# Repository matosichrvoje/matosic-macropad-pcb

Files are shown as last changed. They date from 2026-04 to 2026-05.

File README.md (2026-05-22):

# Matosic Macropad

**Open source programmable keypad with 9 mechanical switches and a clickable rotary encoder.**

A derivative of [ANAVI Macro Pad 10](https://github.com/AnaviTechnology/anavi-macro-pad-10) by [ANAVI Technology](http://www.anavi.technology), redesigned around a Seeeduino XIAO module socket and migrated to KiCad 10. Released under the same Creative Commons Attribution-ShareAlike 4.0 International License (CC-BY-SA-4.0) as the upstream — see [LICENSE](LICENSE).

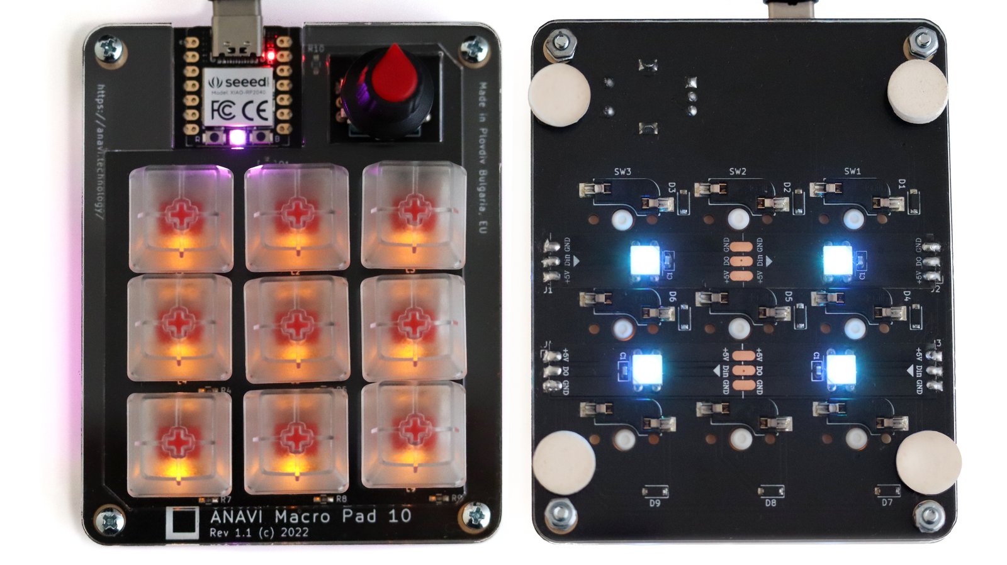
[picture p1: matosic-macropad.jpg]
Matosic Macropad


## Hardware

- 9× Cherry MX (Kailh hot-swap sockets) wired as a 3×3 matrix with per-key 1N4148 anti-ghosting diodes
- 1× clickable EC11 rotary encoder
- **Seeeduino XIAO module socket** — supports any XIAO variant (XIAO RP2040 recommended). USB-C connector and microcontroller live on the XIAO, not on this PCB.
- 9× per-key 1206 SMD LED backlight (single on/off, driven via SOT-23 NPN — not WS2812B)
- 4× 1×3 expansion headers (only J1 carries signal — `R10 → board.D10`; J2/J3/J4 are +5V/GND power taps)
- Designed in KiCad 10 (migrated from the upstream KiCad 5 source)

## Companion firmware

CircuitPython firmware lives in a separate repo: <https://github.com/matosichrvoje/matosic-macropad-firmware>

XIAO pin map for the 3×3 matrix scan and LED chain is documented in [firmware-pinout.md](firmware-pinout.md).

## Case

OpenSCAD sources plus ready-to-print STL/STEP exports live under [case/](case/). Re-export from the `.scad` files after any edit.

## Manufacturing

Target fab is JLCPCB; PCBA is optional (only commodity SMT parts on the board, all hand-solderable). The verified BOM with confirmed LCSC part numbers from the v0.0.0.17 fab run is committed at [bom/matosic-macropad-bom.csv](bom/matosic-macropad-bom.csv) — use it as the source of truth instead of relying on JLCPCB's auto-match. Gerbers + CPL are generated locally by the KiCad **Fabrication Toolkit** plugin into `production/` (gitignored).

## Changes from upstream

This is a derivative work. The substantive changes relative to `AnaviTechnology/anavi-macro-pad-10` are:

- KiCad 5 → KiCad 10 project migration (project file, schematic, PCB, library tables)
- Rebrand from "ANAVI Macro Pad 10" to "Matosic Macropad" — new silkscreen artwork and logo footprint at [components/logo.pretty/matosic-logo.kicad_mod](components/logo.pretty/matosic-logo.kicad_mod). The original Anavi logo footprint is retained at [components/logo.pretty/anavi-logo.kicad_mod](components/logo.pretty/anavi-logo.kicad_mod) for provenance.
- Verified LCSC part numbers for JLCPCB PCBA in [bom/matosic-macropad-bom.csv](bom/matosic-macropad-bom.csv); fab learnings and corrections documented in [CLAUDE.md](CLAUDE.md)
- Renamed all KiCad project files from `anavi-macro-pad-10.*` to `matosic-macropad.*`

The 3×3 switch matrix, encoder wiring, LED-chain topology (single NPN driving 9 LEDs from one GPIO), Kailh hot-swap socket footprint, Seeeduino XIAO module socket footprint, and the case design are inherited from the upstream design.

## Repository files

- `matosic-macropad.kicad_pro`, `matosic-macropad.kicad_pcb`, `matosic-macropad.kicad_sch` — active KiCad 10 project
- `matosic-macropad.sch`, `matosic-macropad.pro`, `matosic-macropad-cache.lib` — pre-migration KiCad 5 backups, kept for safety
- [components/](components/) — bundled footprint/symbol libraries (keyswitches, LEDs, XIAO, logos)
- [case/](case/) — OpenSCAD case sources + STL/STEP exports
- [bom/](bom/) — verified BOM with LCSC part numbers
- [firmware-pinout.md](firmware-pinout.md) — authoritative XIAO pin map for the firmware repo

## Credits

- **Lead:** Hrvoje Matosic
- **Contributors:** Jorge Ochoa, Iván Aceves, Iván Estevez
- **Upstream design:** [ANAVI Technology](http://www.anavi.technology) — *ANAVI Macro Pad 10*, the original work this project is derived from.

## License

This project is released under the [Creative Commons Attribution-ShareAlike 4.0 International (CC-BY-SA-4.0)](https://creativecommons.org/licenses/by-sa/4.0/) license, matching the upstream. The full license text and attribution notice are in [LICENSE](LICENSE).

If you remix or build on this design, you must:

1. **Attribute** Hrvoje Matosic and link back to this repository.
2. **Attribute** the upstream project — [ANAVI Macro Pad 10](https://github.com/AnaviTechnology/anavi-macro-pad-10) by [anavi.technology](http://www.anavi.technology) — as the original design.
3. **ShareAlike** — license your derivative under CC-BY-SA-4.0 (or a BY-SA-compatible license).
4. Indicate what you changed relative to this repo.

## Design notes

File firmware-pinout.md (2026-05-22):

# Firmware pinout — v0.0.0.17

Derived from [matosic-macropad.kicad_pcb](matosic-macropad.kicad_pcb) on 2026-05-18 during the first board bring-up. Use this map when porting [code.py](https://github.com/matosichrvoje/matosic-macropad-firmware/blob/main/code.py) to XIAO RP2040.

## XIAO U1 pin map

The U1 footprint is `xiao:Seeeduino XIAO-MOUDLE14P-2.54-21X17.8MM`. Numbering matches the standard Seeed silkscreen — pin 1 at top-left, pin 14 at top-right.

| KiCad pad | XIAO silk | CircuitPython | Function |
|---|---|---|---|
| 1  | D0  | `board.D0`  | LED enable (Q1 gate) — high turns all 9 LEDs on |
| 2  | D1  | `board.D1`  | ROW 3 — SW7/SW8/SW9 common |
| 3  | D2  | `board.D2`  | ROW 2 — SW4/SW5/SW6 common |
| 4  | D3  | `board.D3`  | ROW 1 — SW1/SW2/SW3 common |
| 5  | D4  | `board.D4`  | COL 1 — outputs of diodes D1/D4/D7 |
| 6  | D5  | `board.D5`  | COL 2 — outputs of diodes D2/D5/D8 |
| 7  | D6  | `board.D6`  | COL 3 — outputs of diodes D3/D6/D9 |
| 8  | D7  | `board.D7`  | Encoder phase B |
| 9  | D8  | `board.D8`  | Encoder phase A |
| 10 | D9  | `board.D9`  | Encoder push-switch |
| 11 | D10 | `board.D10` | Side-connector signal (R10 → J1 pad 2) |
| 12 | 3V3 | — | Power |
| 13 | GND | — | Power |
| 14 | 5V  | — | Power (LED rail through Q1) |

## Key matrix

3×3 with per-key anti-ghosting diodes (D1–D9, 1N4148 SOD-123). Scan by driving each row LOW in turn and reading the column inputs — a pressed key pulls its column LOW through the diode.

| | COL1 (D4)  | COL2 (D5)  | COL3 (D6)  |
|---|---|---|---|
| ROW1 (D3) | SW1 / L1 | SW2 / L2 | SW3 / L3 |
| ROW2 (D2) | SW4 / L4 | SW5 / L5 | SW6 / L6 |
| ROW3 (D1) | SW7 / L7 | SW8 / L8 | SW9 / L9 |

`Lx` is the per-key indicator LED, not part of the switch wiring.

## LEDs

All 9 SMD LEDs (L1–L9) are in parallel, each through its own 68 Ω resistor (R1–R9). Common anode side ties to Q1's drain; Q1's source is +5V; gate is `board.D0`. Drive D0 HIGH → all 9 on, LOW → all off. No per-key control on this revision.

## Encoder (E1)

EC11 style. A = `board.D8`, B = `board.D7`, push-switch = `board.D9`. Common pin grounded. Use CircuitPython's `rotaryio` for the A/B phases and treat the push-switch as a 10th key.

## CircuitPython skeleton

```python
import time, board, digitalio, usb_hid
from adafruit_hid.keyboard import Keyboard
from adafruit_hid.keycode import Keycode

ROWS = [board.D3, board.D2, board.D1]   # ROW1, ROW2, ROW3
COLS = [board.D4, board.D5, board.D6]   # COL1, COL2, COL3
LED_ENABLE = board.D0

row_pins = []
for p in ROWS:
    pin = digitalio.DigitalInOut(p)
    pin.switch_to_output(value=True)    # idle high; pull low to scan
    row_pins.append(pin)

col_pins = []
for p in COLS:
    pin = digitalio.DigitalInOut(p)
    pin.switch_to_input(pull=digitalio.Pull.UP)
    col_pins.append(pin)

led = digitalio.DigitalInOut(LED_ENABLE)
led.switch_to_output(value=True)         # backlight on

kbd = Keyboard(usb_hid.devices)

# KEYMAP[row][col] -> Keycode or tuple of Keycodes for combos.
KEYMAP = [
    [(Keycode.CONTROL, Keycode.SHIFT, Keycode.COMMAND, Keycode.FOUR),  # SW1: screenshot region
     Keycode.X, Keycode.C],
    [Keycode.A, Keycode.S, Keycode.D],
    [Keycode.Q, Keycode.W, Keycode.E],
]
states = [[False]*3 for _ in range(3)]

while True:
    for r, row in enumerate(row_pins):
        row.value = False
        for c, col in enumerate(col_pins):
            pressed = not col.value
            if pressed and not states[r][c]:
                k = KEYMAP[r][c]
                kbd.press(*k) if isinstance(k, tuple) else kbd.press(k)
                states[r][c] = True
            elif not pressed and states[r][c]:
                k = KEYMAP[r][c]
                kbd.release(*k) if isinstance(k, tuple) else kbd.release(k)
                states[r][c] = False
        row.value = True
    time.sleep(0.005)
```

## Bring-up notes (2026-05-18)

- Soldered XIAO via castellated flush mount. Initial joints were balled — insufficient flux + dwell time. Cleaned up with a flux pen, longer iron-on-pad before feeding solder, and less solder per joint. Final joints are taller than ideal but pass continuity and power-up.
- Front-side SMD parts (diodes, resistors, LEDs, Q1) arrived pre-populated from JLCPCB PCBA.
- CircuitPython 10.2.1 boots cleanly; CIRCUITPY mounts over USB.
- A "discovery" firmware that polled D0–D10 as plain pull-up inputs did **not** detect switch presses. Root cause: the design uses a matrix, not pin-per-switch. With rows left floating-high as inputs, no GPIO is connected to ground when a key is shorted — both ends of the switch see the same potential. Must drive rows LOW and read columns.
- Side-connector net `R10 → J1-Pad2` runs to `board.D10`. The other expansion headers (J2/J3/J4) carry +5V/GND only — they're power taps, not signal extensions.

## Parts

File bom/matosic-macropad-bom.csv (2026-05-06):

Comment | Designator | Footprint | Quantity | LCSC Part # | Suggested LCSC | Notes
1N4148 | D1,D2,D3,D4,D5,D6,D7,D8,D9 | SOD-123 | 9 |  | C81598 | Will Semicon — Basic part. Matrix diode for the 3x3 key grid.
LED 1206 white | L1,L2,L3,L4,L5,L6,L7,L8,L9 | LED_1206_3216 | 9 |  | C71796 | KT-1206W (Hubei Kento) — 1206 white LED | Extended (no Basic 1206 white was in stock for the v0.0.0.17 fab run). Verified 1206 (3.2x1.6mm) — do NOT pick KT-0603W C2290 (it's 0603) or XL-1606UWC C965866 (1.7x1.1mm). For color other than white substitute KT-1206R/G/B/Y same series; KT-1206R is cheapest at ~$0.0084.
68R 5% 0603 | R1,R2,R3,R4,R5,R6,R7,R8,R9 | R_0603 | 9 |  | C27592 | Yageo 0603WAF680JT5E (68 ohm 5% 0603) — Basic. Current limit for L1-L9. Same family as R10. v0.0.0.17 fab originally got Extended Yageo RTT0268R0FTH C103146; swapped to this Basic part to skip the $3 Extended setup fee.
470R 1% 0603 | R10 | R_0603 | 1 |  | C23179 | UNI-ROYAL 470 ohm 1% — Basic. Series resistor on rotary encoder switch line (between U1 pin 11 / D10 and E1 switch). NOT a Q1 base resistor — Q1 base ties directly to U1 pin 1 (D0) in this design (upstream Anavi quirk; consider adding a base resistor in a future revision).
NPN BC817-25 SOT-23 | Q1 | SOT-23 | 1 |  | C2146 | S8050 (C2146) is the most common Basic SOT-23 NPN. BC817-25 (C181583) also Basic but Extended fee may apply — verify.
 |  |  |  |  |  | ---- THROUGH-HOLE — recommend hand-solder ----
Kailh hot-swap MX socket | SW1,SW2,SW3,SW4,SW5,SW6,SW7,SW8,SW9 | Kailh_socket_MX | 9 |  | C5184526 | Kailh PG1511 — Basic on JLCPCB. Or buy from a keyboard supplier (cheaper per unit).
Alps EC11 rotary encoder | E1 | RotaryEncoder_Alps_EC11E-Switch_Vertical_H20mm | 1 |  | C2924876 | EC11 with switch 20mm shaft — Basic. Or generic equivalent from AliExpress.
1x3 pin header 2.54mm | J1,J2,J3,J4 | PinHeader_1x03_P2.54mm | 4 |  | C124375 | Standard 2.54mm male header — Basic. Cut from a 40-pin strip.
 |  |  |  |  |  | ---- USER-SUPPLIED ----
Seeeduino XIAO RP2040 (or any XIAO variant) | U1 | Seeeduino XIAO-MOUDLE14P-2.54-21X17.8MM | 1 |  | C2912427 | XIAO RP2040 — buy from Seeed or JLCPCB. NOT included in PCBA. User plugs in.
2x 1x7 socket for XIAO | (part of U1 socket) | PinSocket_1x07_P2.54mm | 2 |  | C146647 | Standard 2.54mm female header — cut from longer strip. Solder these so user can plug XIAO.

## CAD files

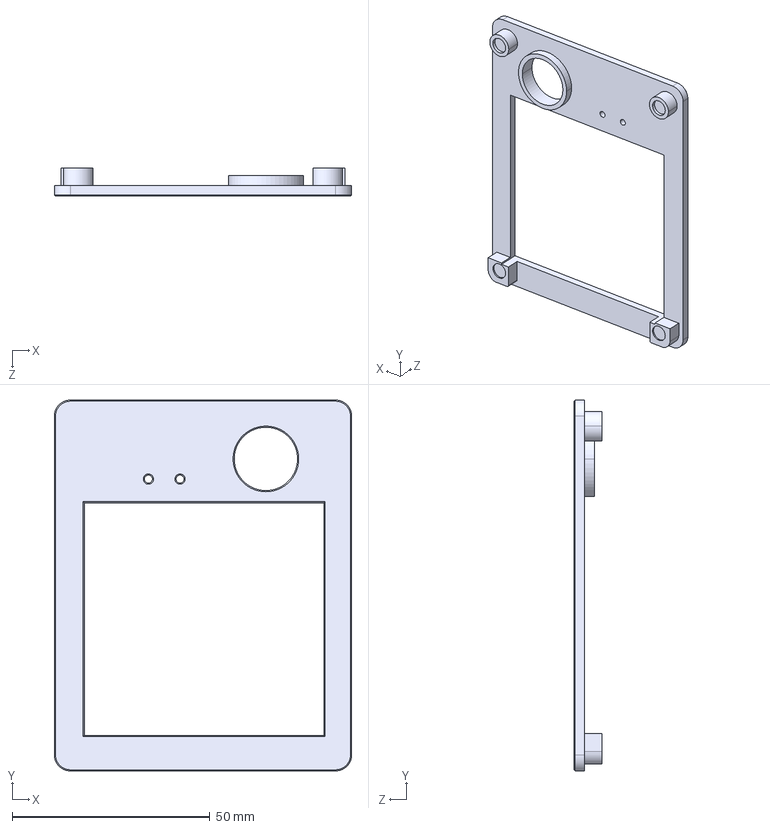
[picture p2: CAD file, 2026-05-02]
case/matosic-macropad-case-top.step
75.2 x 93.8 x 7.10 mm

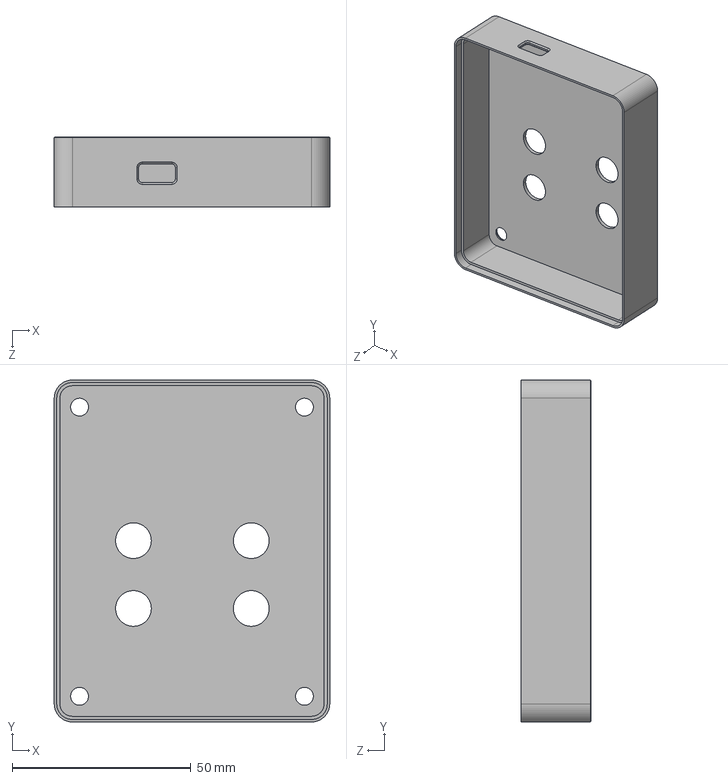
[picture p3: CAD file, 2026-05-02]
case/matosic-macropad-case-bottom.step
77.2 x 95.8 x 19.7 mm

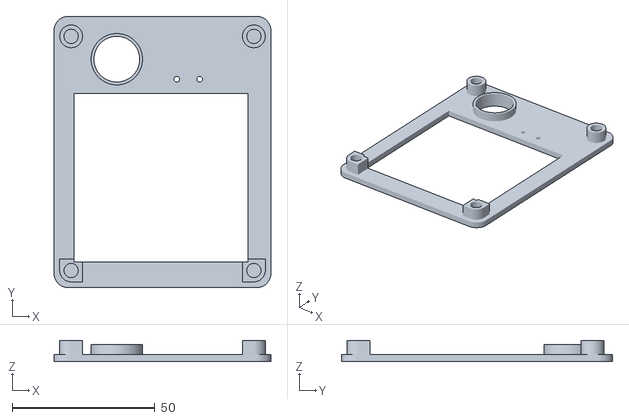
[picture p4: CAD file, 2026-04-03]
case/matosic-macropad-top.stl
76.0 x 95.0 x 7.50

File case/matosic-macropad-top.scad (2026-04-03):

// ========================
// Parameters
// ========================
// PCB corner radius
corner_r = 5;    
// Wall thickness
wall_thickness = 2;  
// smooth corners
$fn = 64;              


// Case (2 mm shorter than the bottom, aka 1 mm on each side)
case_width = 76;
case_lenght = 95;
case_height = 2.5;

// Outer cylinder
outer_r = 4;
outer_h = 5;

// Inner hole
hole_r = 2.5;
hole_h = 4;

// USB-C connector
usbc_l = 10;
usbc_h = 5;

// LED
led_r = 5;

// increase for smoother cone ($fn)
segments = 64;

// ========================
// Case Top Module
// ========================

module case_top() {
    difference() {
        
        // Translate so inner PCB pocket starts at (0,0)
        union() {
            
            translate([corner_r, corner_r, 0])
            // Outer shell (walls included)
            linear_extrude(height = case_height)
                rounded_rect(case_width,
                             case_lenght,
                             corner_r);
            
            // Rotary encoder border
            translate([13+9, 71+9, 0])
                cylinder(6, 9, 9, $fn = segments);
            
            // Bottom left
            translate([2, 2, case_height])
                mounting_hole(true);
            
            // Bottom right
            translate([case_width-2*outer_r-2, 2, case_height])
                mounting_hole(false);
            
            // Top left
            translate([2, case_lenght-2*outer_r-3, case_height])
                mounting_hole_round();
            
            // Top right
            translate([case_width-2*outer_r-2, case_lenght-2*outer_r-3, case_height])
                mounting_hole_round();
        }
        
        // Inner hollow segment of the keycaps
        translate([7, 9, 0])
            cube([61, 59, 30]);
        
        // Opening for the rotary encoder
        translate([14+8, 72+8, 0])
            cylinder(6, 8, 8, $fn = segments);
        
        // Openings for the buttons
        translate([43, 73, 0])
            cylinder(3, 1, 1, $fn = segments);
        
        translate([51, 73, 0])
            cylinder(3, 1, 1, $fn = segments);
    }
    
}

// ========================
// Rounded rectangle module
// ========================
module rounded_rect(x, y, radius) {
    minkowski() {
        square([x - 2*radius, y - 2*radius], center = false);
        circle(r = radius, $fn = $fn);
    }
}

// ========================
// Mounting holes
// ========================
module mounting_hole_round() {
    // Position at start
    translate([outer_r, outer_r, 0]) {
        difference() {
            // Outer cylinder
            cylinder(h = outer_h, r = outer_r, $fn = segments);
            
            // Inner hole
            translate([0, 0, outer_h-hole_h])
                cylinder(h = hole_h, r = hole_r, $fn = segments);
        }
    }
}

module mounting_hole(left = true) {
    tr = left ? 0 : -outer_r;
    // Position at start
    translate([outer_r, outer_r, 0]) {
        difference() {
            
            union() {
                // Outer cylinder
                cylinder(h = outer_h, r = outer_r, $fn = segments);
                translate([tr, -outer_r, 0])
                    cube([4, 8, outer_h]);
                translate([-outer_r, 0, 0])
                    cube([8, 4, outer_h]);
            }
            
            // Inner hole
            translate([0, 0, outer_h-hole_h])
                cylinder(h = hole_h, r = hole_r, $fn = segments);
        }
    }
}

// ========================
// Top case
// ========================

case_top();

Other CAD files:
case/matosic-macropad-bottom.scad
case/matosic-macropad-case-bottom.stl
case/matosic-macropad-case-top.stl

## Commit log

2026-04-03 anavi-macro-pad-10-top: Change hole height
    Increase inner hole height from 2 to 4mm to simplify the process
    of placing brass threaded inserts with a special tool.
    [anavi-macro-pad-10-top.scad, anavi-macro-pad-10-top.stl]
2026-05-02 Fork to Matosic Macropad: rebrand, KiCad 10 migration, first JLCPCB BOM
    - Migrate KiCad source v5 → v10 (.kicad_pcb, .kicad_sch, .kicad_pro)
    - Rename project files anavi-macro-pad-10.* → matosic-macropad.*
    (case files, cache, jpg, pcb, sch, pro, sch-bak)
    - Update internal references in .kicad_pro, .kicad_pcb, .pro
    - Replace front silkscreen with Matosic branding (MATOSIC, v0.0.0.17,
    "designed by Hrvoje Matosic"); remove Anavi front-side branding
    - Add Matosic 3D logo footprint and place on B.SilkS
    - Add contributor list (Jorge Ochoa, Iván Aceves, Iván Estevez) on B.SilkS
    - Populate schematic title block with Matosic branding + CC-BY-SA-4.0
    attribution to Anavi
    - Fix component val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
    [anavi-macro-pad-10-bottom.scad, anavi-macro-pad-10-case-bottom.step, anavi-macro-pad-10-case-bottom.stl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]
2026-05-04 Document v0.0.0.17 fab learnings and correct BOM LCSC numbers
    - bom/matosic-macropad-bom.csv: replace guessed LCSC numbers with
    verified ones from the v0.0.0.17 JLCPCB submission:
    - L1-L9: C2286 (red guess) -> C71796 (KT-1206W, verified 1206 white)
    - R1-R9: C25092 (UNI-ROYAL guess) -> C27592 (0603WAF680JT5E, Yageo
    Basic 68R, same family as R10)
    - project notes file:
    - Fix upstream URL typo (anavi-macro-pad-10, was matosic-macropad)
    - Repo layout: KiCad 10 (not v5) + note legacy .sch / .pro are pre-
    migration backups
    - Manufacturing: Gerbers/BOM/CPL now generated; bom CSV is committed
    - Active tasks: tick off v0.0.0.17 work; surface v0.0.0.18 backlog
    - Silkscreen check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
    [emisha-macropad-bom.csv]
2026-05-06 Correct R10 description in BOM
    R10 is the rotary encoder switch series resistor (between U1 pin 11
    and E1), not the Q1 base resistor. Q1 base ties directly to U1 pin 1
    in this design (upstream Anavi quirk). Identified during JLCPCB part
    placement review for v0.0.0.17.
    [emisha-macropad-bom.csv]
2026-05-07 Tighten solder-mask tolerances for JLCPCB
    - Drop explicit solder_mask_min_width 0.25 override (use KiCad default).
    - Set solder_mask_to_copper_clearance: 0.0 -> 0.005 mm.
2026-05-18 gitignore .notes-cache/ (per-machine internal docs tool settings)
    `.notes-cache/settings.local.json` holds permission allowlists and other
    local internal docs tool state — machine-specific, shouldn't be shared across
    clones or contributors.
2026-05-19 Document v0.0.0.17 bring-up: XIAO pin map + project notes file refresh
    - Add firmware-pinout.md as the authoritative XIAO RP2040 pin map for
    porting code.py, derived from matosic-macropad.kicad_pcb and verified
    during the 2026-05-18 board bring-up. Includes matrix wiring, encoder
    pins, LED enable polarity, and a CircuitPython skeleton.
    - project notes file: update v0.0.0.17 status (boards arrived, XIAO soldered,
    CP boots); correct expansion-header description (only J1 carries
    signal via R10 -> D10; J2/J3/J4 are +5V/GND power taps); add the
    bring-up insight that switches form a 3x3 matrix, not pin-per-switch.
2026-05-21 Update v0.0.0.17 status: bring-up complete; expand v0.0.0.18 planning
    - Mark white LED chain + first-key macro as confirmed working (2026-05-20)
    - Flag that the working code.py is on the office machine, not yet pushed
    - Expand v0.0.0.18 wishlist with open design decisions: bare RP2040 vs
    XIAO socket trade-off, MCP23017 GPIO expansion, OLED footprint,
    CircuitPython to QMK+VIA migration, cost-reduction levers, reference
    designs to study
    - Fix sym-lib-table portability note: line 4 has a stale absolute path
    that contradicts the project-portable claim
    - Expand .gitignore description to cover the bom/*.csv allow-list and
    other rules that survived the last refresh
2026-05-21 Compact v0.0.0.17 status: collapse done items into one paragraph
    Bring-up is complete — the per-step checklist served its purpose during
    the work, but as a permanent record it's noisy. Keep the two ⏳ items.
2026-05-21 Rebrand project notes file to Matosic Macropad
    Drop the 'Matosic' product name from all prose. Filenames on disk
    (matosic-macropad.kicad_*, BOM CSV, .scad files, firmware repo URL)
    stay as-is to preserve git history — naming-note at the top of the
    file explains the situation.
    Silkscreen checklist updated for v0.0.0.18: matosic wordmark + new
    matosic logo footprint to be drawn. Anavi attribution requirements
    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
2026-05-22 Rename matosic-* to matosic-* across PCB project + scrub legacy brand
    17 files renamed via `git mv` so KiCad's internal rename tracking is
    preserved. Internal references updated everywhere they appeared:
    - matosic-macropad.kicad_pro / .kicad_pcb / .kicad_sch: filename
    cross-references between the KiCad project, PCB, and schematic;
    cache-lib reference; logo footprint reference.
    - matosic-macropad.kicad_pcb: silkscreen `gr_text` "MATOSIC" -> "MATOSIC".
    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
    [matosic-macropad-bom.csv, matosic-macropad-bottom.scad, matosic-macropad-case-bottom.step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]
2026-05-22 Prep for first public release: LICENSE, strengthen Anavi attribution, queue OSHWA cert
    LICENSE: NOTICE header + canonical CC-BY-SA-4.0 text. Credits ANAVI
    Technology as the upstream and declares ShareAlike on this derivative.
    README.md: drops "private during development" status; reworks intro
    as derivative-of statement using Anavi's requested
    http://www.anavi.technology URL; adds "Changes from upstream" and
    "License" sections; fixes Files block to reference .kicad_sch (KiCad
    10 active) instead of the legacy .sch backup.
    project notes file: queues OSHWA certification as an Active task and adds
    OSHW mark + UID to the v0.0.0.18 B.SilkS checklist (recommended by
    Leon Anavi in response to the c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
2026-05-22 Untrack project notes file; gitignore project notes file and local project notes so internal docs tool project memory stays local-only
    The previous public/local split required judging what's safe to
    expose per-section, which is error-prone. Simpler pattern: keep all
    internal docs tool project memory entirely local. No project notes file committed
    from now on — contributor-facing docs live in README.md and LICENSE,
    which are the canonical public-facing files.
    Both project notes file and local project notes are gitignored in case the
    split-file pattern is ever reintroduced; neither should ever be
    committed.
